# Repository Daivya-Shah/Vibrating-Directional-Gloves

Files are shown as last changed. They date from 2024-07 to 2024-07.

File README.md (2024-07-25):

# Vibrating Directional Gloves (VDG)

## Overview

The Vibrating Directional Gloves (VDG) project aims to enhance driving safety by providing tactile feedback for GPS directions. These gloves utilize haptic feedback to indicate 'turn left' and 'turn right' commands, making driving safer and more intuitive. The project integrates speech recognition and vibration motors controlled by an Arduino Nano 33 BLE Sense.

## Project Contributors

- Daivya Shah (dts7992@nyu.edu)
- Kaylee Weber (kew6119@nyu.edu)
- Jiangnan Wang (jw7572@nyu.edu)

## Project Advisors

- Professor Rui Li (rui.li@nyu.edu)

## Features

- **Tactile Feedback**: Provides vibrations on the left or right glove to indicate GPS directions.
- **Speech Recognition**: Utilizes Edge Impulse for training models to recognize 'turn left' and 'turn right' commands.
- **Arduino Integration**: Uses Arduino Nano 33 BLE Sense to process and execute commands.

## Components

### Hardware
- Arduino Nano 33 BLE Sense
- Vibration Motors
- Breadboard, wires, resistors, diode rectifier, NPN transistor, 3V power source
- 3D-printed frame for housing components
- Nike sock used to create a comfortable and low-cost glove

### Software
- **Edge Impulse**: For collecting and training speech samples.
- **Arduino IDE**: For programming the Arduino Nano 33 BLE Sense.

## Installation

### Hardware Setup
1. Assemble the circuit on the breadboard with Arduino Nano 33 BLE Sense, vibration motors, and other components as described in the [circuit diagram](./CircuitDiagram.png).
2. Secure the Arduino and components in the 3D-printed frame.
3. Attach the frame to the glove made from a Nike sock using Velcro.

### Software Setup
1. Train the speech recognition model on Edge Impulse with samples of 'turn left', 'turn right', and 'noise'.
2. Download the trained model from Edge Impulse as an Arduino library.
3. Install necessary libraries in Arduino IDE:
   - `Adafruit_ZeroPDM-Master`
   - `Arduino BLE-1.3.2`
   - `Project2_inferencing` (downloaded from Edge Impulse)
4. Upload the code to Arduino Nano 33 BLE Sense.

## Usage
1. Wear the gloves and connect the Arduino to a power source.
2. The gloves will vibrate based on the GPS commands 'turn left' and 'turn right' recognized by the speech recognition model.

## Project Schedule and Costs

### Schedule
- **Start Date**: October 9
- **End Date**: November 10
- **Advanced Functions and Extra Credit**: Post-November 10

### Cost Breakdown
- **Initial Estimate**: $7,640
- **Final Cost**: $2,540.59

## Challenges and Solutions
- **Vibration Motor Circuit**: Issues with wiring diagrams were resolved through research and planned capacitor addition.
- **Speech Recognition**: Limited experience required extensive experimentation with Edge Impulse.

## Future Improvements
- Enhance the device to read numerical signals for more detailed feedback.
- Expand applications for visually or auditory-challenged individuals.

## References
- [How We Feel Touch](https://askabiologist.asu.edu/explore/how-do-we-feel-touch)
- [Response Time to Stimuli](https://www.iaeng.org/publication/IMECS2012/IMECS2012_pp1449-1454.pdf)
- [US Drivers Statistics](https://usafacts.org/data/topics/people-society/transportation/safety/licensed-drivers/)
- [GPS Dependency](https://www.carpro.com/blog/where-drivers-are-most-dependent-on-gps-systems)
- [Circuit Diagram](https://www.circuito.io/app?components=514,8449,11022)
- [Speech Recognition with Arduino](https://circuitdigest.com/comment/33907#comment-33907)

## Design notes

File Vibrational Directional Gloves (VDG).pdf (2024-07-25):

## Vibrational Directional Gloves (VDG)

## Project Report

### Daivya Shah (dts7992@nyu.edu)

### Kaylee Weber ( kew6119@nyu.edu)

### Jiangnan Wang (jw7572@nyu.edu)

### Professor Rui Li (rui.li@nyu.edu)

### Engineering Design 1004

### New York University Tandon School of Engineering

### December 6th, 2022

## Introduction

The primary objective of this project was to create gloves that vibrate to help drivers by providing

tactile responses to GPS directions, either left or right. Tactile signals were utilized for several reasons,

such as the fact that skin consists of at least three different types of receptors that interpret different touch

sensations (1). Additionally, the human response time to tactile stimuli is "28% and 34% shorter than that

of auditory and visual stimuli" (2), where the increased response time could be valuable in a driving

environment. A focus was placed on driving since there were 228 million drivers in the U.S. in 2020 (3),

and a survey in 2022 found that 93% of drivers depend on their GPS every day (4). GPS is a tool that

focuses solely on auditory and visual communication, forcing drivers to take their eyes off the road or

listen to the rarely repeated directions that Siri states before approaching an intersection. Therefore, the

Vibrating Directional Gloves (VDG) aim to add a tactile element to GPS and driving to make the roads

safer and drivers more confident.

The VDG focuses almost entirely on a speech recognition system designed to understand when

the GPS states "left" or "right" before a turn. Once that phrase is understood, the Arduino components

send the proper signals to a vibration motor on the corresponding glove. This system will allow drivers to

feel more confident about where they are going and help those prone to zoning out on long car rides know

which way they will be turning. Further applications of the VDG include the potential to prevent car

crashes due to last-minute lane switching or the need to look at a GPS rather than the road. Currently, the

VDG could help the hard of hearing and the directionally challenged feel more confident while driving.

Additionally, the VDG can help the everyday person who may zone out or not pay attention to their GPS

while driving.

## Requirements

### 1. Physical Components

The design for the VDG is centered around an Arduino Nano 33 BLE Sense and vibration motors.

Additional circuit-related components include a breadboard, wires, resistors, a diode rectifier, an NPN

transistor, and a 3V power source. The circuit is designed to allow the Arduino Nano to control the

vibration motors when responding to the auditory input and vibrate the correct motor based on that input.

The entire Arduino circuit is contained in a small, 3D-printed frame designed to be worn on the forearm.

3D printing the frame has allowed the design to remain lightweight while still being sturdy enough to

secure the Arduino components. The 3D-printed model is placed in a sleeve and is secured to the glove

using Velcro. The glove and sleeve are both constructed using a Nike sock, allowing the design to remain

comfortable and low-cost.

### 2. Software Requirements

The software focused heavily on a website called Edge Impulse. Edge Impulse is a free online

resource that helps developers collect data and structure it in various formats. Edge Impulse was utilized

to train the speech samples of "turn left" and "turn right" so that a program could recognize the phrases.

Other elements of the software included the Arduino IDE, which uses the programming language C++.

Multiple external libraries were downloaded to the Arduino IDE for the program to recognize the Arduino

Nano 33 BLE Sense and the commands in the code generated from Edge Impulse. These libraries

included Adafruit_ZeroPDM-Master, Arduino BLE-1.3.2, and the file from Edge Impulse named

Project2_inferencing.

### 3. Project Schedule

The projected schedule starts on October 9 and ends on November 10, lasting for 33 days. The

time after November 10 will be focused on advanced functions for extra credit.

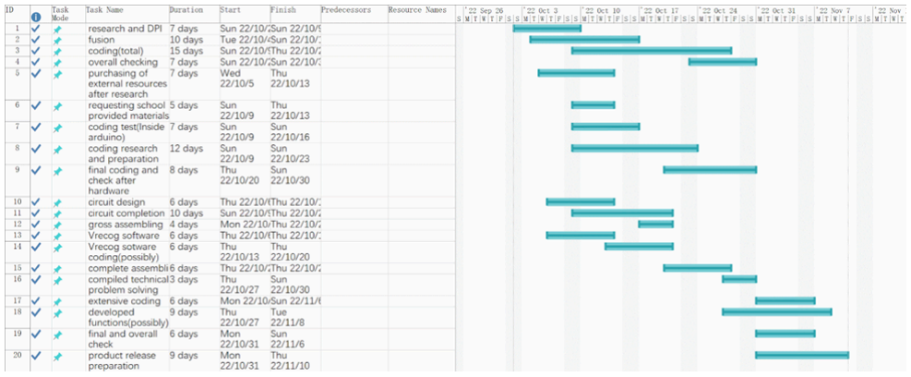
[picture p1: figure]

### 4. Cost Schedule

The initial cost estimate was expected to be within $7,640. As the team progressed, the final cost

estimate was determined to be $2,540.59.

RESOUR CE | COST(PER UNIT) | MS1 | MS2 | MS3
QUANTIT Y | COST | QUANTIT Y | COST | QUANTIT Y | COST

3D Printing material | undetermin ed | undetermin ed | <10 | undetermin ed | <10 | N/A | N/A
Vibrators | 1.3 | 2 | <20 | 2 | <20 | 2 | 2.6
Microphon e and Arduino | External source | 1 | <100 | 1 | <100 | 1 | 37.99
straps | undetermin ed | undetermin ed | undetermin ed | N/A | undetermin ed | N/A | N/A
Speech detection | undetermin ed | undetermin ed | undetermin ed | Arduino | Arduino | Edgeimpul se | N/A

Projected labor | 50 | 150 | 7500 | 150 | 7500 | 50 | 2500
TOTAL | | <$7640 | | <$7640 | | 2540.59

## Procedures

### 1. Physical Construction

The physical construction of the VDG required two main elements: the CAD model to hold the

Arduino components and the glove itself. The CAD model was developed in two phases. The first phase

was eight inches long and built with two levels. The bottom level rested against the forearm of the user,

and the top level held the Arduino components. The upper level of the CAD model was originally

designed to hold an Arduino Uno and a breadboard. This was amended when it was decided that the

Arduino Nano 33 BLE Sense would be used for the project, which would rest directly on the breadboard.

The space for the Arduino Uno was converted into a battery holder, and the overall length was decreased

to seven and a half inches so that the design could be printed with the Ultimakers. The final CAD model

was printed using PLA printing material.

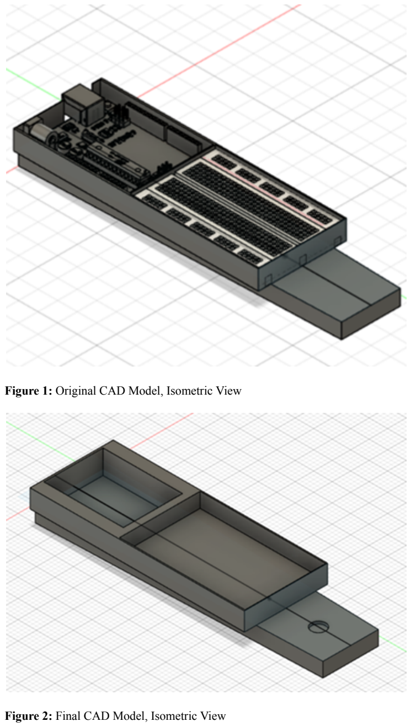
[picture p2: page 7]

Figure 1: Original CAD Model, Isometric View

Figure 2: Final CAD Model, Isometric View

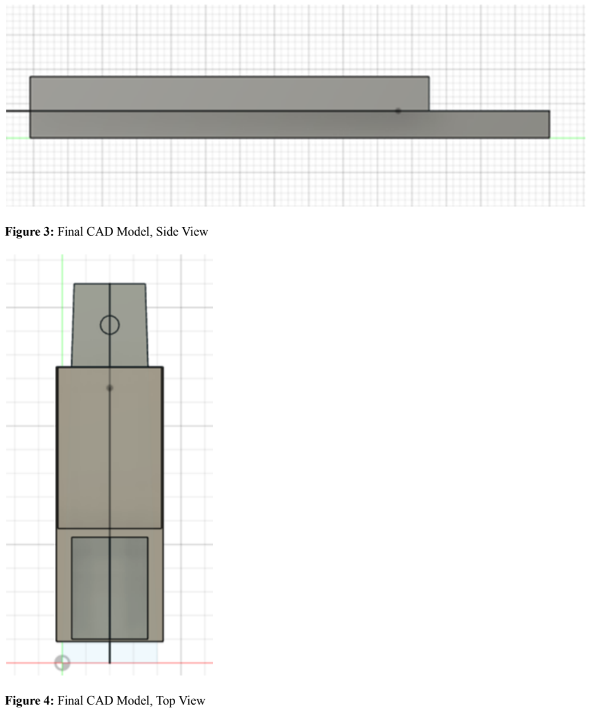
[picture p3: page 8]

Figure 3: Final CAD Model, Side View

Figure 4: Final CAD Model, Top View

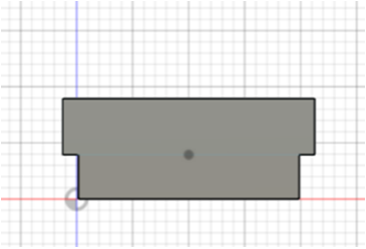
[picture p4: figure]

Figure 5: Final CAD Model, Front View

The glove was originally meant to be a true glove that would go over the hand of the user. When

it became apparent that the design would have to be large to accommodate the Arduino components, the

focus shifted to the forearm. The glove was made from a recycled Nike sock for its comfort, length, and

low-cost option. Construction began by cutting the sock right above the heel. A hole was cut into the side

of the sock to allow the user's thumb to fit and hold the sock in place. The remainder of the foot of the

sock was found to be roughly the same size as the printed CAD model. The foot of the sock was placed

over the CAD model to contain the Arduino components. The CAD model and the rest of the glove were

secured together by wrapping Velcro around both components, securing the device to the user's forearm.

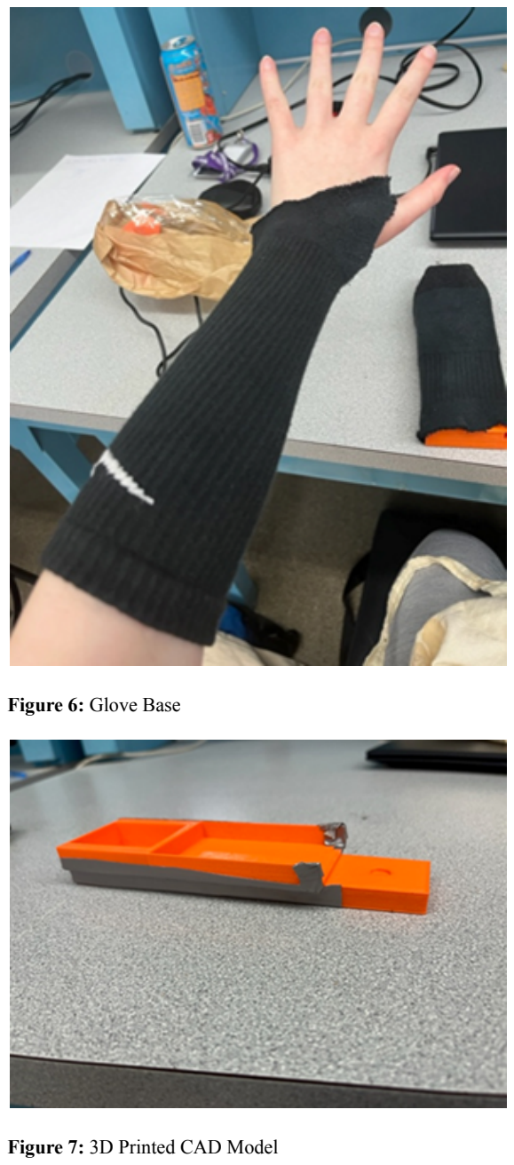
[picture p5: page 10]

Figure 6: Glove Base

Figure 7: 3D Printed CAD Model

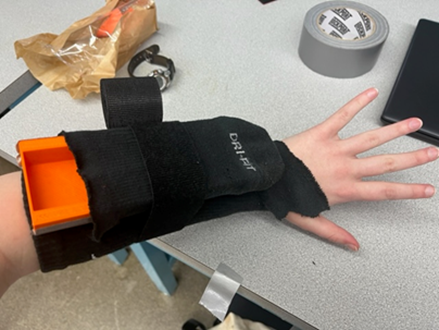
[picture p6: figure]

Figure 8: Wearable Assemble

The other main element of the physical construction was the Arduino circuit for the vibration

motors. The circuit included the Arduino Nano 33 BLE Sense, a breadboard, wires, resistors, a diode

rectifier, an NPN transistor, and a 3V power source. Problems arose when it was realized that the wiring

done with the Arduino Uno for the vibration motors was not applicable, and new circuit diagrams had to

be found. The circuit was wired in accordance with the specifics listed on Circuito.io (cite source, 5).

Unfortunately, the circuit that was found did not appear to be functional, and no other easily accessible

wiring diagrams existed. Research into forums around this issue yielded inconclusive results. If time

permitted, the next step would have been to add a 100 nF capacitor, which was seen in many posts, and

test the new circuit with the Arduino Nano 33 BLE Sense.

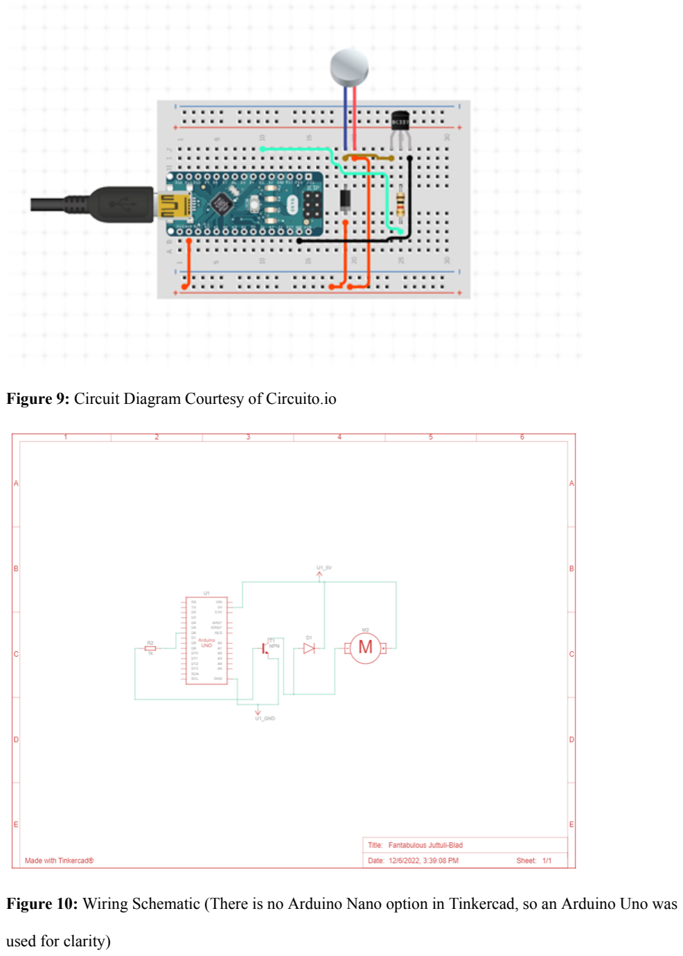
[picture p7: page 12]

Figure 9: Circuit Diagram Courtesy of Circuito.io

Figure 10: Wiring Schematic (There is no Arduino Nano option in Tinkercad, so an Arduino Uno was

used for clarity)

### 2. Software Setup

The software setup was done almost entirely using Edge Impulse. To train a program to

understand an automated voice saying "turn left" and "turn right," Edge Impulse was used to eliminate

user error. Projects were built using the free "developer" option on Edge Impulse, and a category for the

data to be used was selected—in this case, audio. The next step was to collect various audio files of "turn

left," "turn right," and "noise." Thirty samples of "turn left," thirty samples of "turn right," and twenty-six

"noise" samples were used in the final project. Edge Impulse automatically split the data into training and

testing datasets, with 83% for training and 17% for testing. An "impulse" had to be created to train the

data. The impulse includes the "window size" (how long the clips were expected to be), the "window

increase" (how many training steps the data would run through), the "processing block" (MFCC audio

was used to recognize voice commands), and a "learning block" where the "Classification (Keras)" option

was selected.

Once the impulse was created, the next step was to run the data through the specified parameters

and check the accuracy of the data recognition. Steps for this process were followed from CircuitDigest

(cite source, 6). The neural network of the classification learning block was edited using the code

provided by CircuitDigest to allow the program greater flexibility for voice recognition. The final overall

accuracy for the project was 76.5%. When the training was completed on Edge Impulse, the program was

exported to an Arduino library file named Project2_inferencing. The zipped folder was downloaded into

the Arduino IDE along with the "Adafruit_ZeroPDM - Master" and "Arduino BLE-1.3.2" libraries to

allow the code to compile. The code successfully compiled; however, due to minimal prior knowledge of

coding, the program was difficult to understand. Therefore, there was difficulty in transferring the steps

obtained from CircuitDigest into a new format. Unfortunately, this learning process was slow and could

not be completed in the allowed time frame.

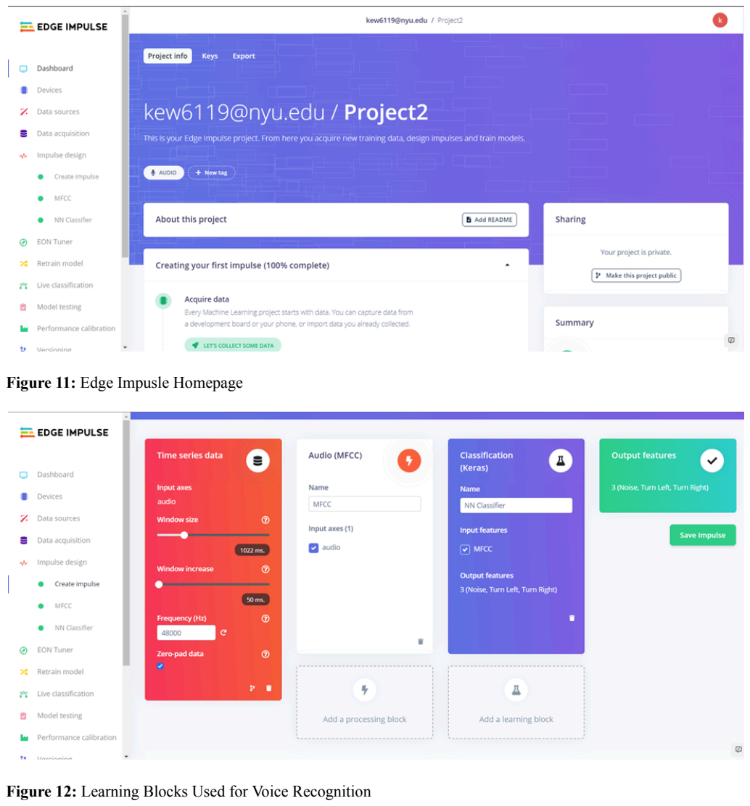
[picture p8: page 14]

Figure 11: Edge Impusle Homepage

Figure 12: Learning Blocks Used for Voice Recognition

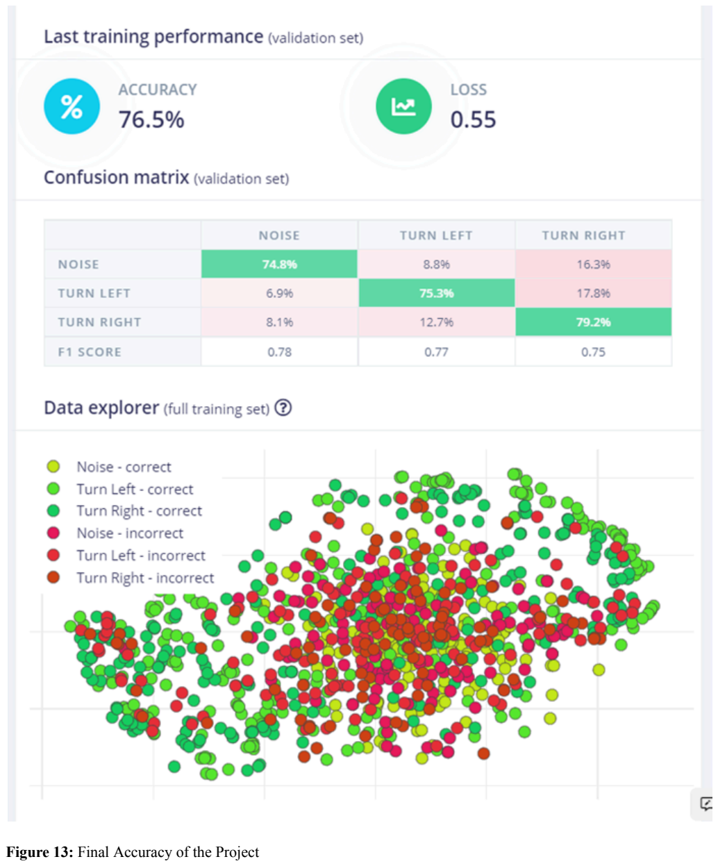
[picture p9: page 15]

Figure 13: Final Accuracy of the Project

### 3. Software Troubleshooting

Problems inevitably arose due to limited knowledge on the topic of speech recognition and

Arduino. Regarding vibration motor circuits, extensive research was done. A somewhat helpful tool was

forums on the Arduino website itself, where other posts were made by designers to ask for help from the

community. While the problems posted did not directly match the circuit and issues encountered in the

construction of the VDG, many similar problems were found. Unfortunately, not all the postings had an

"answer" to the problem, and many different postings were researched to find common denominators for

wiring the vibration motor circuit. Through this research, it was discovered that the vibration motor circuit

for an Arduino Nano was different from the circuit required for the Arduino Uno. Conflicting answers

were found regarding the Arduino Nano circuit; however, commonalities suggested that the Arduino

Nano circuit required an additional diode and possibly a 100 nF capacitor. Unfortunately, due to the time

it took to research these topics, this solution was not able to be implemented.

Regarding the speech recognition side of the project, many roadblocks were encountered. There was no

prior experience with Edge Impulse or speech recognition, and a lot of experimentation was done with the

website to understand its functionality. Multiple different projects were created through the website to test

different aspects of the training program and the factors that controlled the speech recognition accuracy.

One project was created with a minimal dataset—ten samples for each category—to test how adjusting

the "window increase" changed the accuracy. It was discovered that decreasing the "window increase"

generated more training steps and was able to increase the accuracy of a project. Meanwhile, a separate

project was examined to understand the difference between using an automated versus human voice. The

dataset for the project was minimal; however, the initial results suggested that human voices might be

easier to decode, prompting the addition of more automated voice recognition samples in the main project

to balance the discrepancy. Unfortunately, raising the accuracy of the voice recognition was not an exact

science, as there were many competing variables at play. Contrary to prior belief, the addition of more

voice samples did not always raise the accuracy, adding to the complexity of the project.

## Milestone and Final Product Requirements

Benchmark A was completed by the end of Model Shop Session II. The requirements for

Benchmark A included the initial CAD model, preliminary design investigation, team logo, updated

engineering notebook, and specific requirements assigned by the RAD mentor. The requirements had to

be checked by an Open Lab TA to complete the benchmark.

For the VDG, the Benchmark A requirements were:

- Initial CAD model
- Completed preliminary design investigation
- Updated engineering notebook
- Logo submission in .STL or .gcode file
- Arduino code flowchart to take in two separate inputs and output to the two vibrators. One input

should turn on vibrator 1, and the other input should turn on vibrator 2.

- Completed circuit with the two vibrators that will take in two different inputs to turn on the

corresponding vibrator. The circuit should be built in Tinkercad.

- Research on speech recognition

Benchmark A early submission was due on Tuesday, October 4th. Regular submission was due at

the end of Open Lab on Sunday, October 16th. Similar to Benchmark A, Benchmark B included an

updated CAD model, a team logo approved through the 3D Printing Submission portal on the EG website,

an updated engineering notebook, and specific requirements outlined by a RAD mentor.

The Benchmark B requirements for the VDG were:

- Updated CAD model
- Updated engineering notebook

- Logo approval in Proto Lab by a Proto TA
- Make the device functional. The Arduino code should be working, meaning it will take in an

input (left or right) and turn on two different vibrators based on the input. Turn on the left vibrator

if the input is "left," etc.

- Create a wearable glove and assemble the Arduino onto the wearable to model the device. The

wearable must hold the Arduino with enough support. Assembly should be complete and

removable.

- Printed CAD model to be assembled (this includes casing, support, anything required to assemble

the wearable)

Benchmark B early submission was due on Tuesday, October 25th. Regular submission was due

at the end of lab on Tuesday, November 1st. Early final submission was due at the end of the lab on

Tuesday, November 29th. Regular final submission was due at the end of the lab on Tuesday, December

6th.

The following items were expected from all RAD groups:

- Final presentation
- Circuit Diagram
- Schematic Diagram
- Code Flowchart
- Commented code
- All CAD drawings of your design
- Video advertisement of the prototype in use
- Final Microsoft Project schedule
- Final cost estimate
- Resume

- Final Engineering Notebook
- Final Design Report

The distribution of work assigned Daivya Shah as the head of programming, Kaylee Weber as the

head of design, and Jiangnan Wang as the head of production. Other requirements stipulated that at least

one group member had to receive MakerSpace training for 3D printing on Ultimakers to print CAD

designs. Kaylee Weber and Jiangnan Wang both received online training and in-person check-ins to use

the Ultimaker printers. No further training on advanced 3D printers was necessary for the project.

## Results

The Benchmark A tasks assigned were all completed by the end of Open Lab on Sunday,

October 16th. These tasks included an initial CAD model, the preliminary design investigation,

an updated engineering notebook, a submitted logo design, a code flowchart that takes two

separate inputs and vibrates two separate vibrators accordingly, and a completed circuit with two

different inputs and their corresponding vibrators on Tinkercad. The Benchmark A tasks were

approved by Aden Lin.

The Benchmark B tasks assigned were all completed by the end of the lab on November

8th. The tasks required included an updated CAD model, an updated engineering notebook, a

logo approved by the Proto Lab TAs, functional Arduino code that could take input of left or

right and turn on the correct vibrator, and a wearable glove assembly that could support the

Arduino components. The Benchmark B tasks were approved by Sydney Blum.

Various obstacles were encountered, and these were apparent by Benchmark B. During

Benchmark A, there was hesitation and confusion regarding how to complete the speech

recognition. The problem was later addressed with advanced research into speech recognition, and Edge Impulse was found to be the solution. The largest problem occurred during Benchmark

B due to the lateness of the Arduino Nano 33 BLE. The problem was addressed through

communication and negotiation with Professor Li, who allowed the team to complete the

benchmark the week after receiving the Arduino Nano 33 BLE Sense. Benchmark B was

completed with an approved time extension.

## Conclusion

The team succeeded in software development using Edge Impulse; however, limited

understanding of code prohibited further development with the generated Arduino code. Additionally,

unresolved circuit challenges and the delayed arrival of the necessary Arduino caused unexpected delays,

leading to partial commissioning. Despite this, the project is not a failure. The team is the first to use the

Arduino Nano 33 BLE, a specific type of Arduino aimed at speech recognition. Online test results

revealed its high accuracy and potential. All efforts of team members were appreciated. Given more time,

the functional product could be fully developed. At this stage, due to our high level of completion, several

future improvements can be anticipated.

The device is expected to read numbers, not just words, allowing it to send not only qualitative

signals (left or right) but also quantitative signals, such as changing vibration frequency in accordance

with the distance from the crossing or direction points as spoken by the GPS. This advanced function only

requires additional construction blocks in the software development, which can be updated and improved

simultaneously. This methodology of transforming different types of signals can also be applied to other

fields. With further development and safety enhancements, similar products may allow visually or

auditory-challenged individuals to receive tactile sensations, applicable in various aspects of their lives

beyond driving. Future developments of the product, aimed at promoting human well-being and

functionality, hold significant potential and promise.

## Works Cited

1. https://askabiologist.asu.edu/explore/how-do-we-feel-touch
2. https://www.iaeng.org/publication/IMECS2012/IMECS2012_pp1449-1454.pdf
3. https://usafacts.org/data/topics/people-society/transportation/safety/licensed-drivers/.
4. https://www.carpro.com/blog/where-drivers-are-most-dependent-on-gps-systems#:~:text=93%25

%20Of%20Drivers%20Depend%20On%20GPS&text=In%20fact%2C%20researchers%20say%2

093,would%20get%20lost%20without%20it (https://www.carpro.com/blog/where-drivers-are-most-dependent-on-gps-systems)

5. https://www.circuito.io/app?components=514,8449,11022
6. https://circuitdigest.com/comment/33907#comment-33907

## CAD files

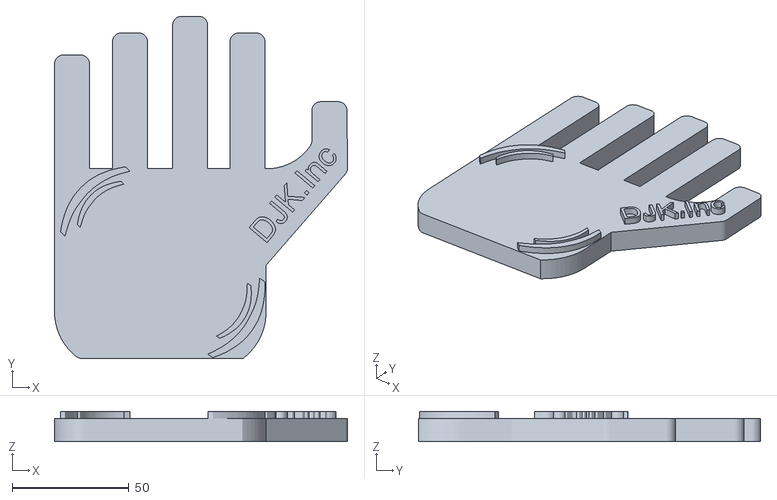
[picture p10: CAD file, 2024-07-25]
Logo/DJK Hand .stl
125.4 x 146.6 x 13.0

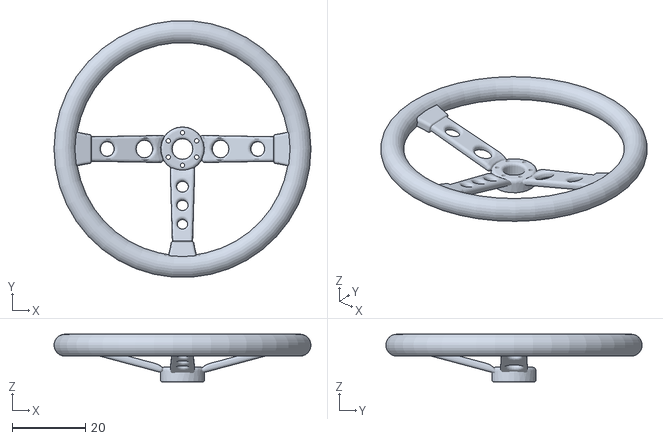
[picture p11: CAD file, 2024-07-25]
Logo/DJK Steering Wheel .stl
70.0 x 69.8 x 13.0
